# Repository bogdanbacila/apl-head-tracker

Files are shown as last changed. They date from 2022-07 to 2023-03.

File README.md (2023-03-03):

# APL Head Tracker

## A basic inexpensive head tracker based on the GY-521/MPU6050 sensor and [MrHeadTracker](https://git.iem.at/DIY/MrHeadTracker) project 

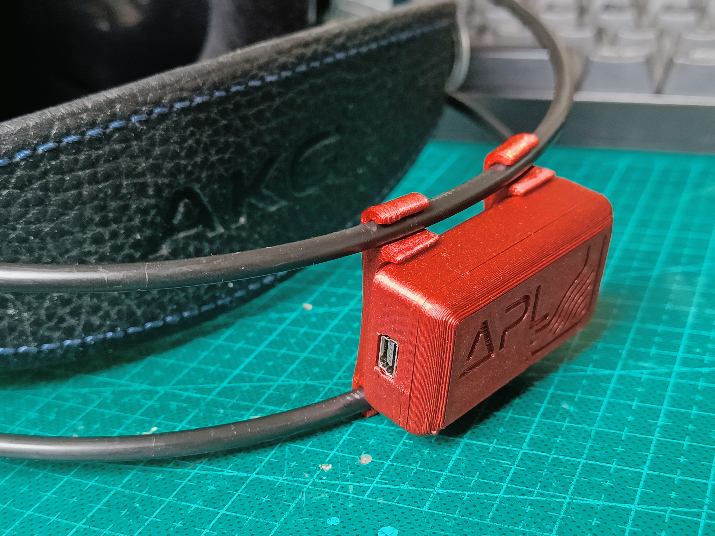
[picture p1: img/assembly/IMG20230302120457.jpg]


A head simple head tracker which connects to the computer through a USB cable and communicates rotation information through serial messaging, in both quaternion and YPR angles.

This head tracker is designed to work best with the APL OSC Bridge. 

### Requirements:

> The Amazon links are shown for illustrative purposes. You can source the parts from the supplier that is most convenient for you.

- 1 pc. Arduino Nano V3 - (recommended the mini-usb version). [Amazon link](https://www.amazon.co.uk/ELEGOO-ATmega-Nano328P-compatible-offical/dp/B072BMYZ18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)
- 1 pc. GY-521/MPU6050 IMU [Amazon link](https://www.amazon.co.uk/AZDelivery-MPU-6050-Gyroscope-Accelerometer-Arduino/dp/B07N2ZL34Z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)
- 1 pc. APL tracker PCB shield: GRBL and SVG files can be found in the [pcb-shield](/pcb-shield/) folder, for home-manufacturing of the PCB shield. Alternatively, PCB shields could be professionally manufactured by companies such as JLCPCB, PCBWay, etc. 
- 1 pc. Micro push button (6 x 6 x 5 mm). [Amazon link](https://www.amazon.co.uk/Youmile-100-Pack-Miniature-Momentary-Tactile-6-x-5-mm/dp/B07Q1BXV7T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)
- 1 pc. 2-bit DIP switch. [Amazon link](https://www.amazon.co.uk/sourcing-map-Horizontal-Positions-Breadboards/dp/B07MH6W9QD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)
- 1 pc. 7 pin header.
- 2 pc. 5 pin header.
- Enclosure: STL or 3MF files can be found [here](enclosure/) for home-printing of the enclosures. 

## Build instructions:

Make sure you have all the components available before starting the build:

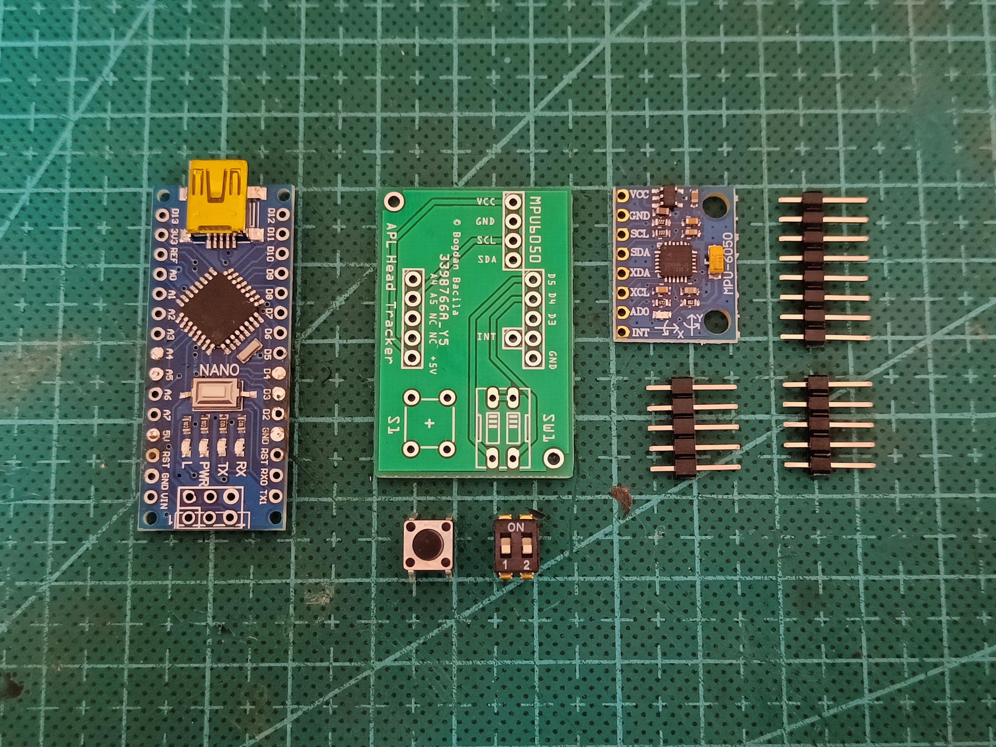
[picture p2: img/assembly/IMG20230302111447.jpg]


### **Step 1:**

Start by preparing MPU-6050 gyroscope break-out board. Solder the 7-pin header **facing up** on the board. 

>**ATTENTION!:** Do not solder pins **XDA, XCL** and **ADO**. These will be removed later. 

| | |
|-|-|
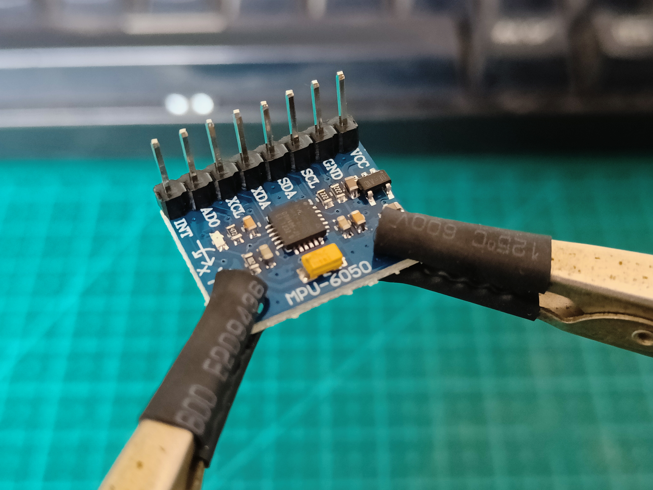
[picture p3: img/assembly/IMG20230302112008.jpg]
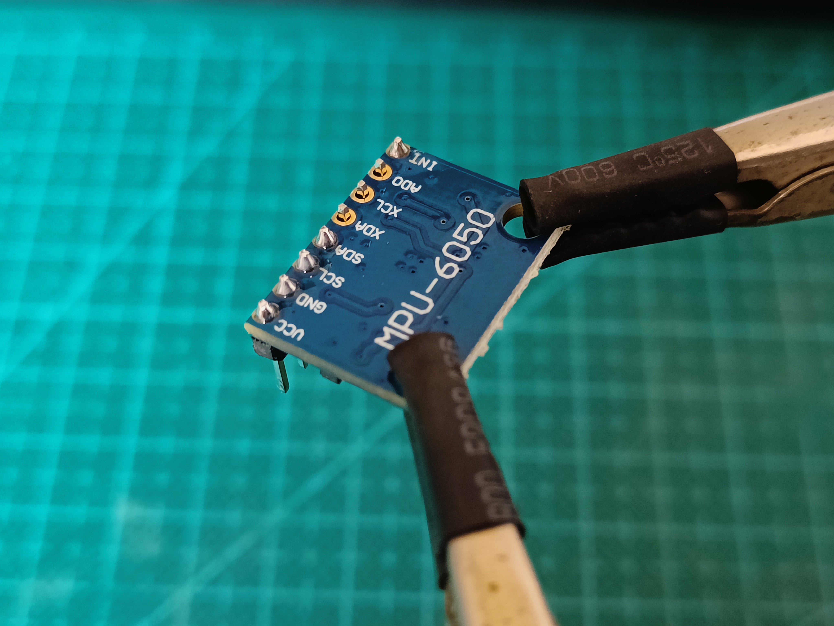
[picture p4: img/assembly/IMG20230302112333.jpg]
|||

Using a pair of pliers, carefully remove pins **XDA, XCL** and **ADO**:

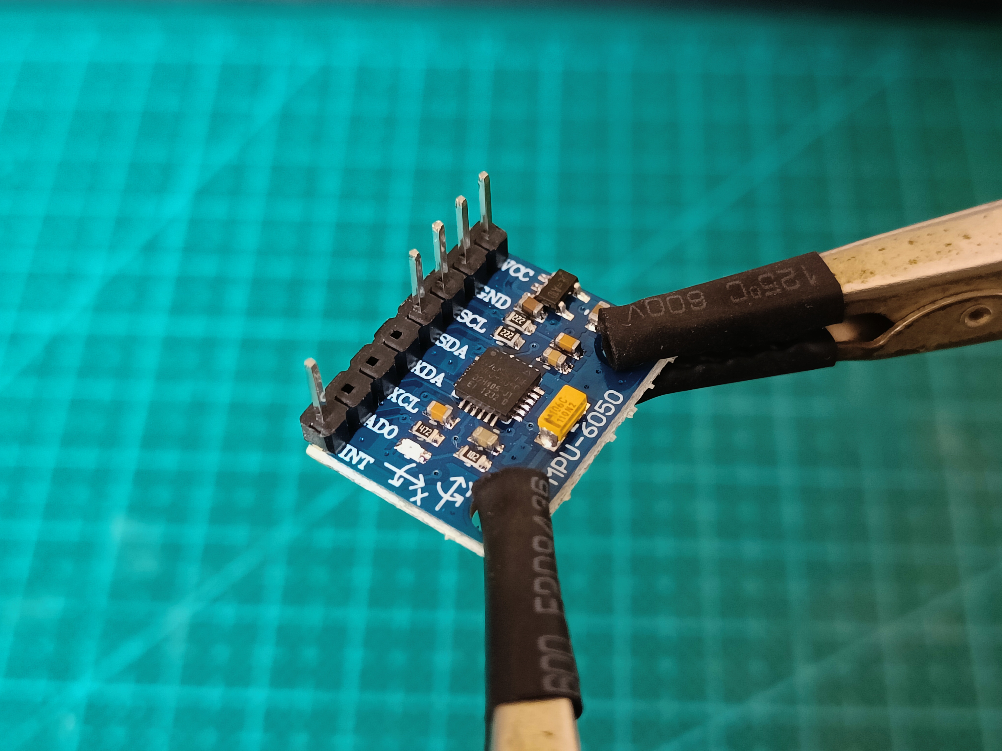
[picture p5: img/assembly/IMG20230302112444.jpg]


### **Step 2:**

Prepare the PCB shield: 

Start by soldering the micro-switch and the 2-pin dip-switch. 

| | |
|-|-|
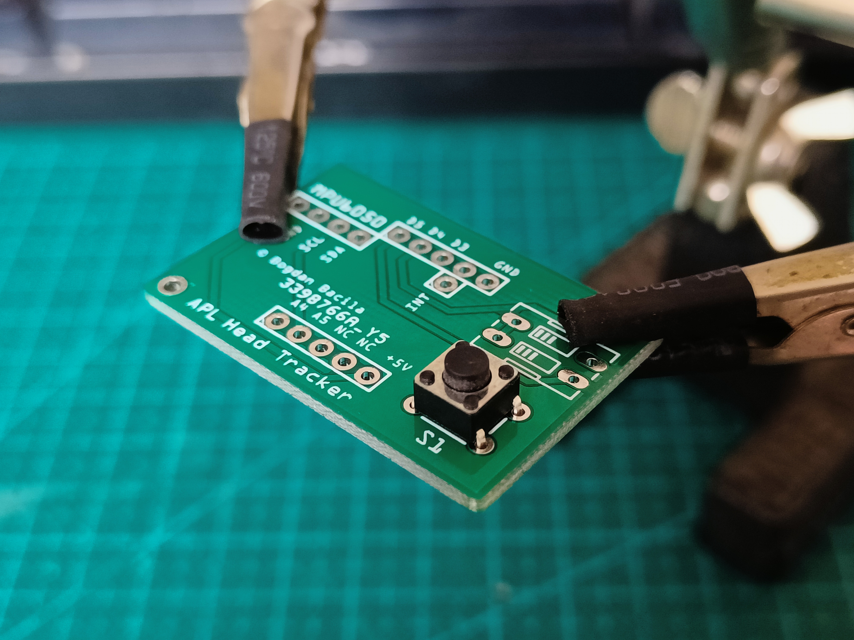
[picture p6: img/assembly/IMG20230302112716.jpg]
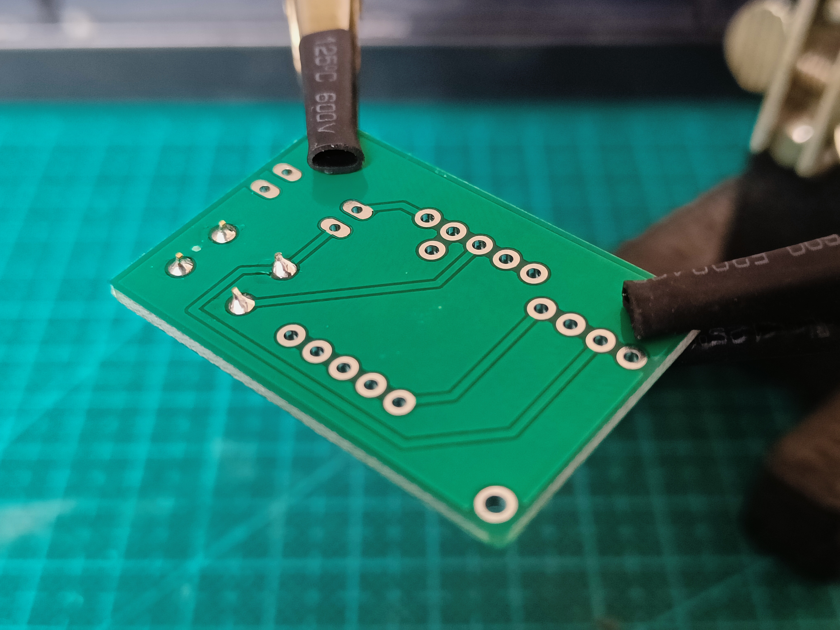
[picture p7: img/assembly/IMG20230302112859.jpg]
||
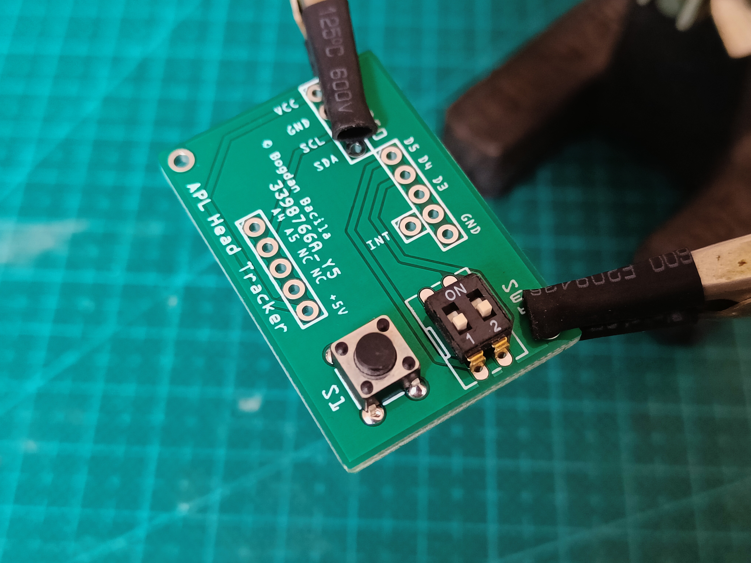
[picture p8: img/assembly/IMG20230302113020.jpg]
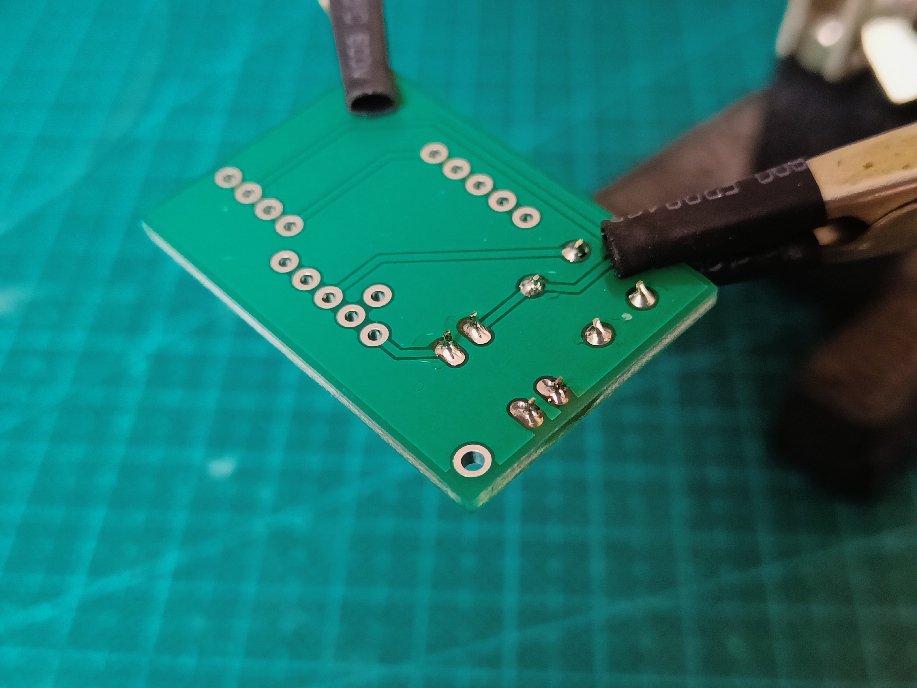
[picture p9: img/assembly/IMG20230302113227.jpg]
||

Next, solder the two 5-pin headers to the **bottom** of the PCB shield. Make sure they are soldered square to the board, otherwise it may not fit properly to the Arduino. 

| | |
|-|-|
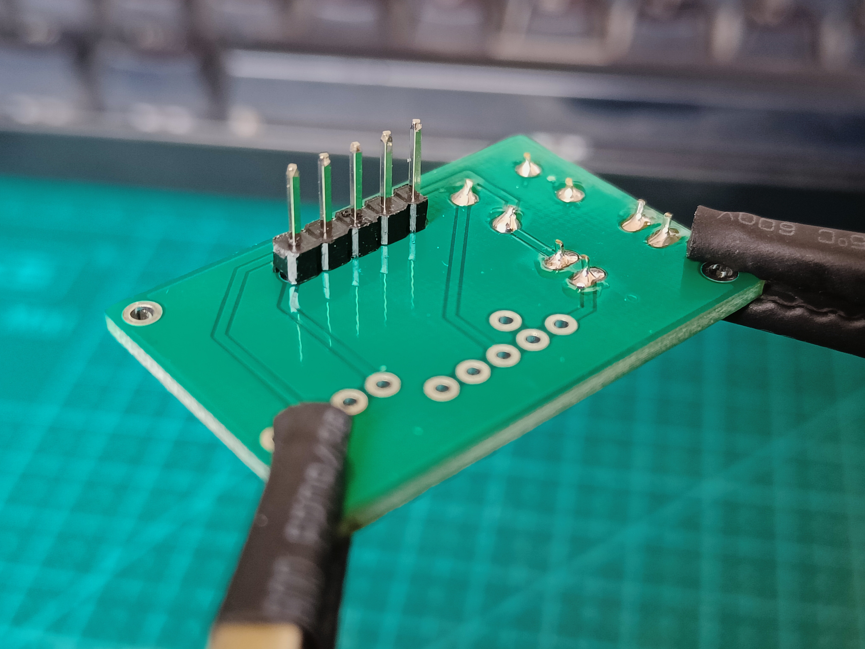
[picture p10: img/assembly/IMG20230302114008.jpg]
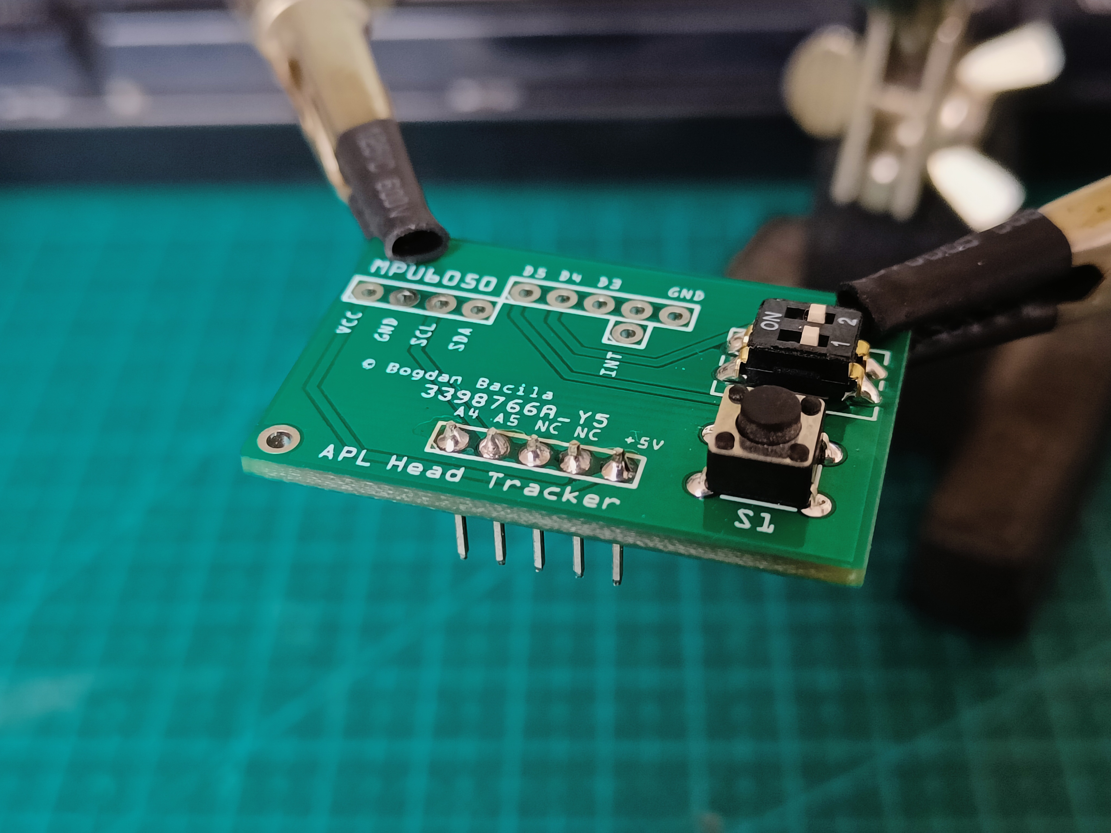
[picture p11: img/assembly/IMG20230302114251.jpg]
||
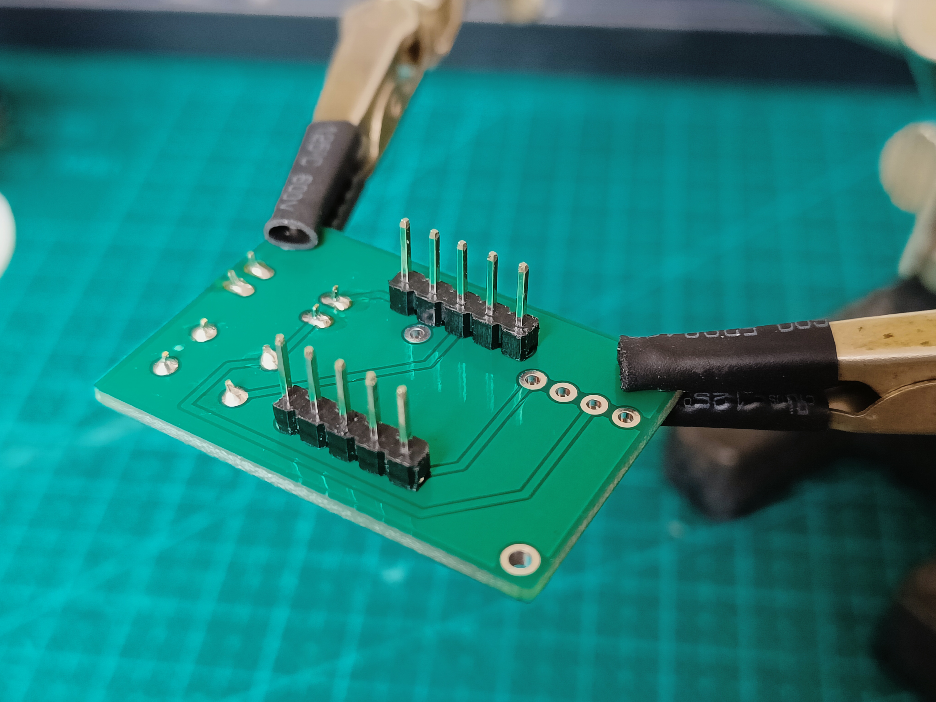
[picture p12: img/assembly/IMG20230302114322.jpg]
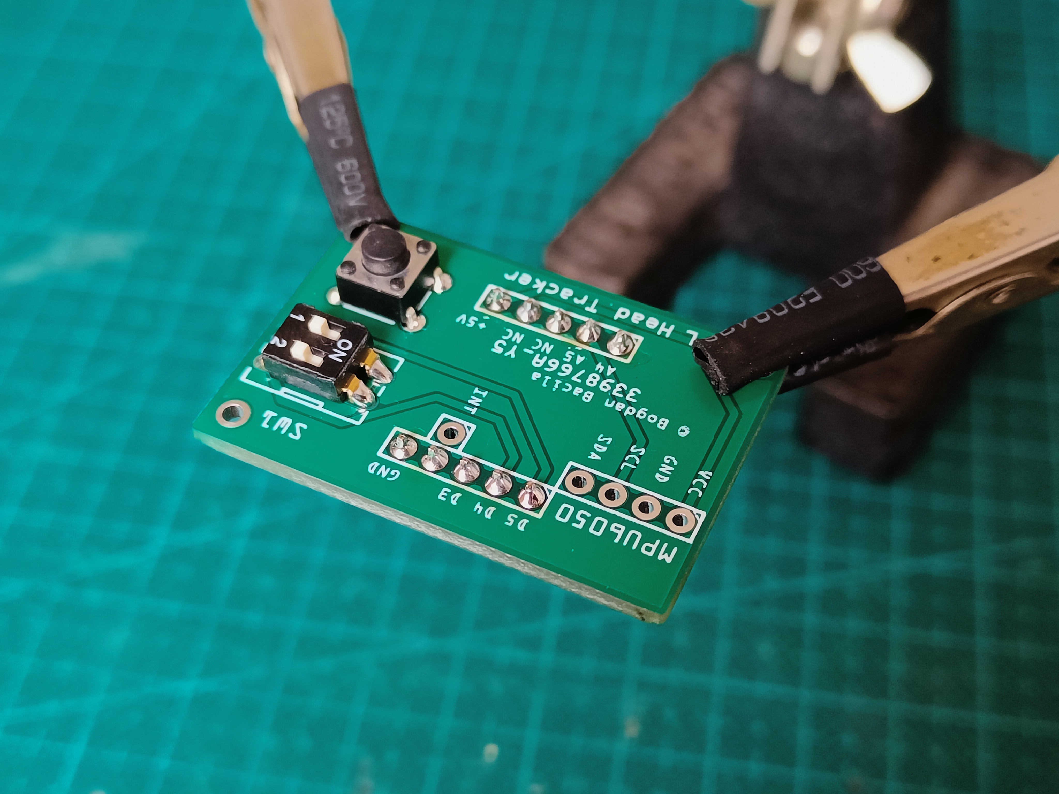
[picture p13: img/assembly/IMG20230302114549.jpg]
||

### **Step 3:**

Solder the MPU-6050 to the **top** of PCB shield, making sure to match the pins on the gyroscope to the pins written on the shield. 

| | |
|-|-|
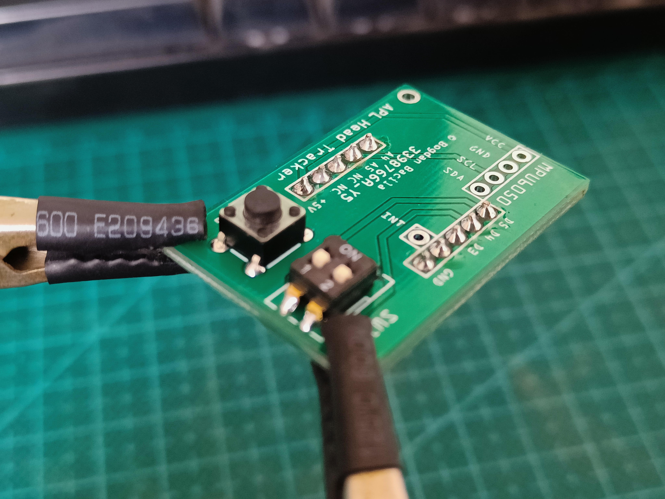
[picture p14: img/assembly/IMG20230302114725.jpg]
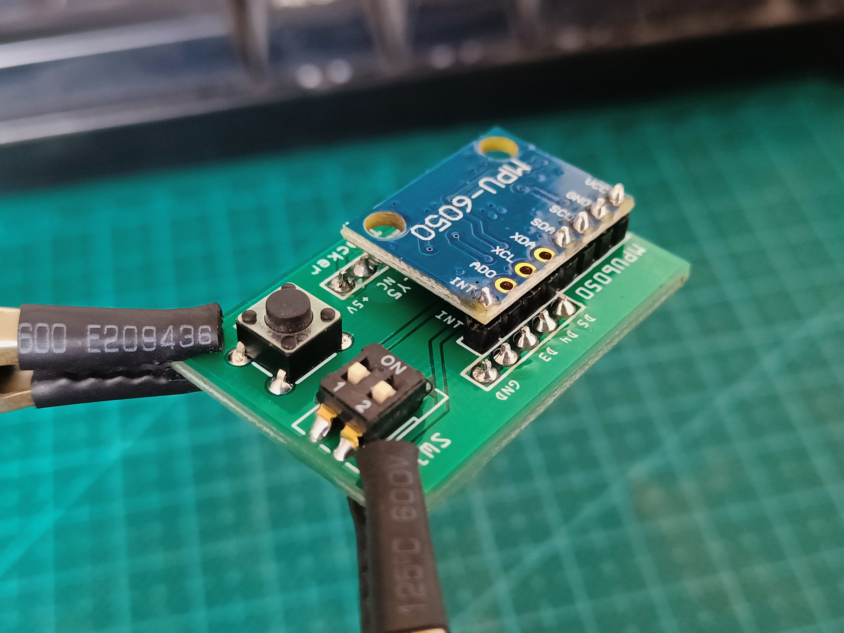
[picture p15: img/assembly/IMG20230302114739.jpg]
||

With a pair of flush cutters, carefully cut the excess header pins from the bottom of the PCB shield. This is necessary to ensure the shield can be soldered flush to the Arduino. 

| | |
|-|-|
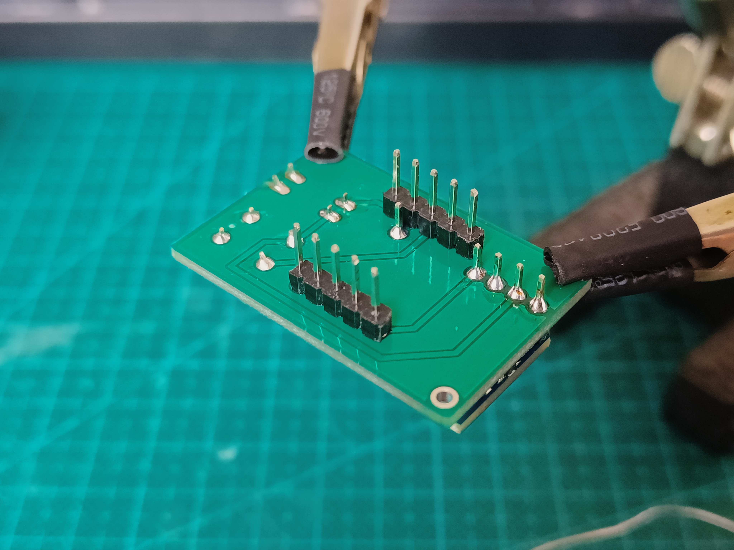
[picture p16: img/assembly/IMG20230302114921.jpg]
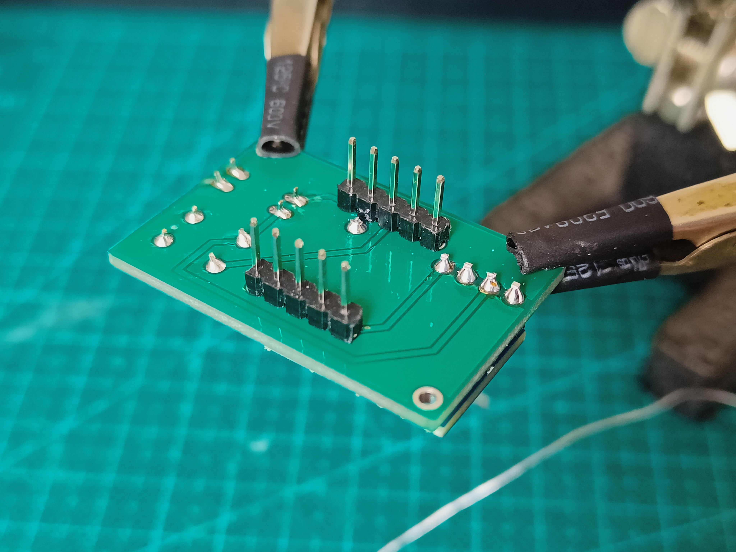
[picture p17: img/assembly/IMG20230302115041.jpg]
||

You have now built the core of the head tracker!

| | |
|-|-|
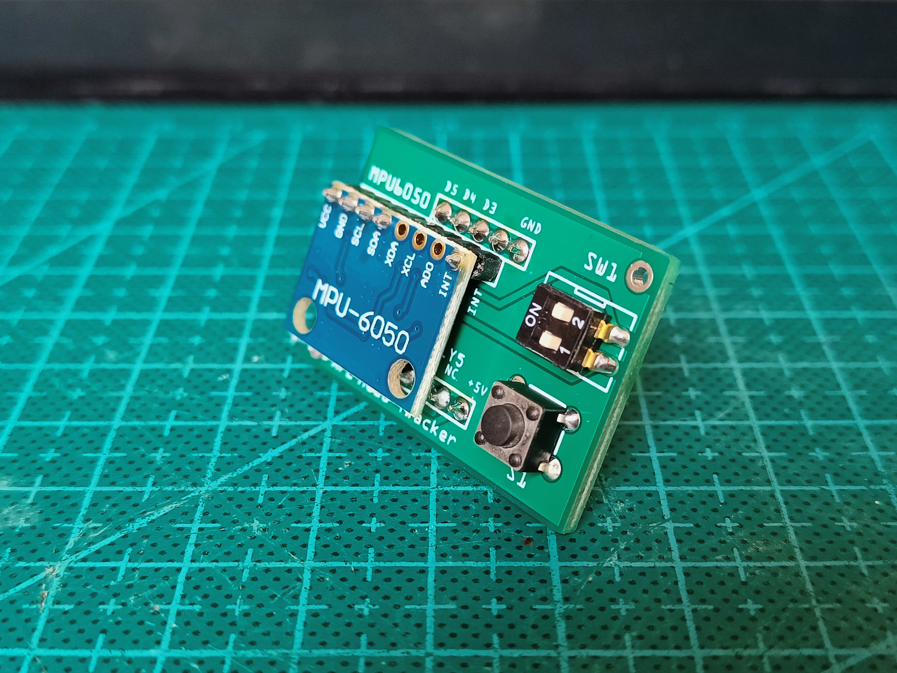
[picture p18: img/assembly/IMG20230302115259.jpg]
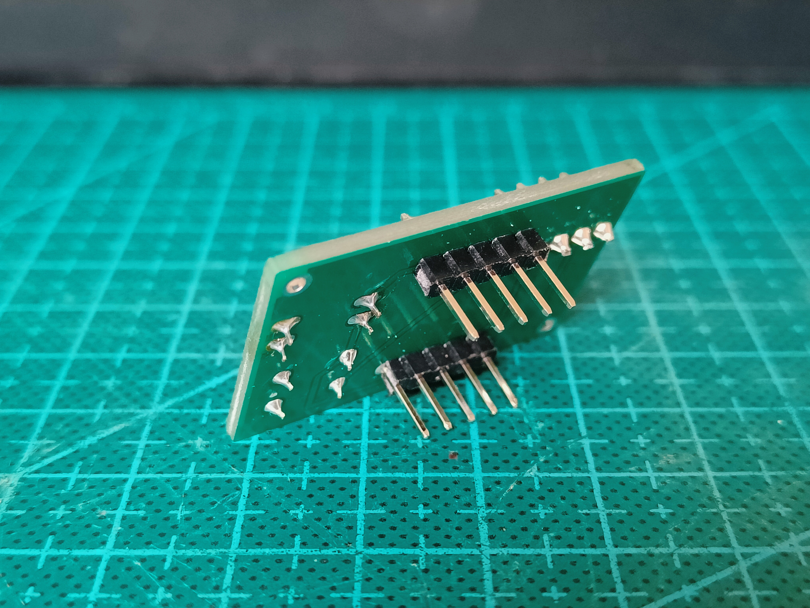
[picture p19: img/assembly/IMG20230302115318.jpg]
||

### **Step 4:**

Solder the PCB shield to the **top** of Arduino, making sure to match the pins on the shield to the pins on the Arduino. Snip the excess pins flush to the Arduino board to ensure a good fit in the enclosure. 

| | |
|-|-|
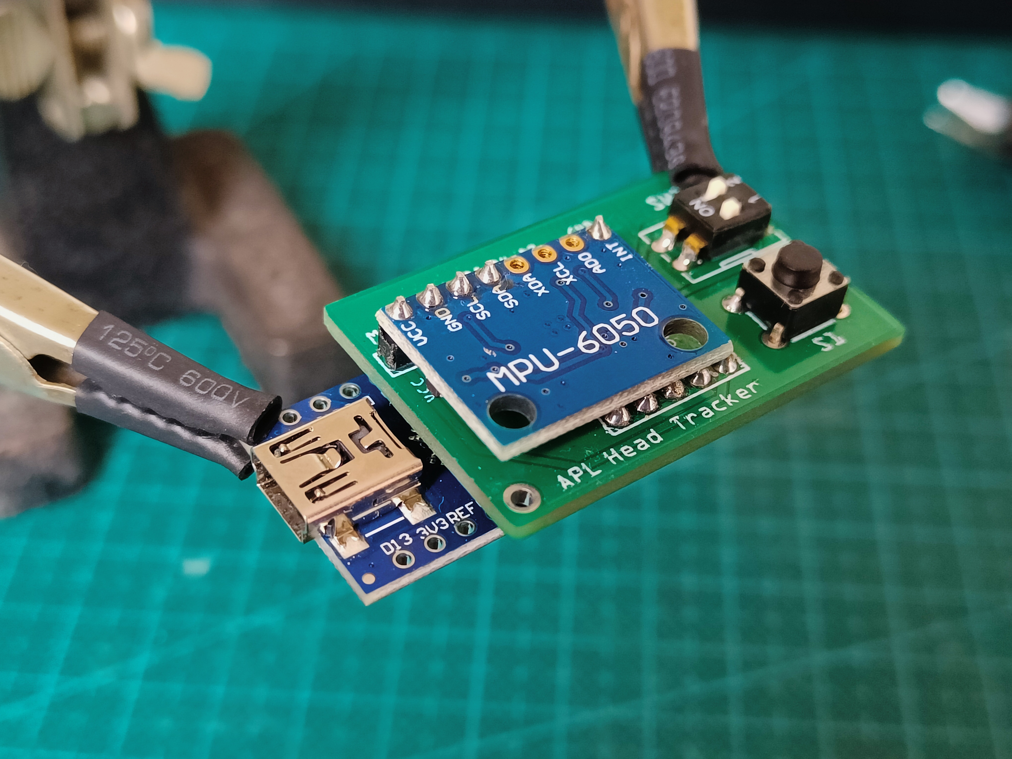
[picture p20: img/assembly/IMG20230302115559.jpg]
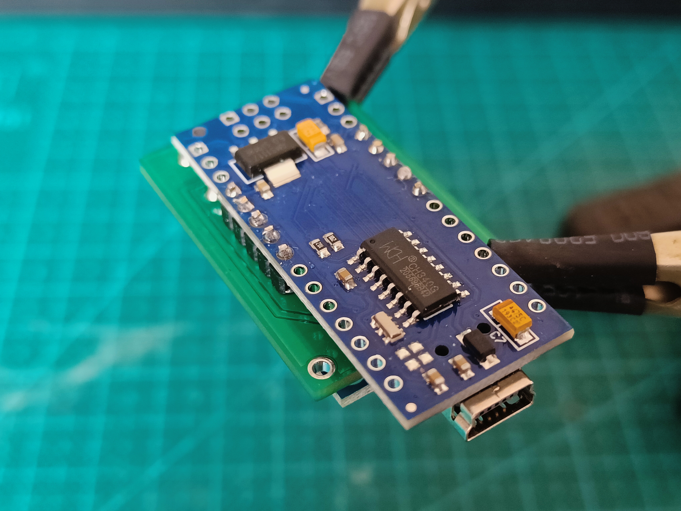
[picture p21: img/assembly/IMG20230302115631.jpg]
||

Now you can set the micro switches as desired: 

- Switch No.1 changes between Quaternions and Yaw-Pitch-Roll output
- Switch No.2 changes between normal and inverse 

To ensure compatibility with the APL OSC bridge, please set the switches as seen in the pictures above: switch no.1 set to on and switch no.2 set to off.

The electronic part of the head tracker is now finished, and you can start using it after flashing the firmware. However, if you own a 3D printer, you can also print an enclosure from the [STLs](/enclosure/) provided:

### **Step 5:**

Make sure all the parts are printed. If additional cleaning of the prints (de-burring or sanding) is required, this would be a great moment for it. Place the head tracker in the enclosure, making sure that the USB port fits the slot in the side. The tracker should be held in place in the enclosure by friction alone. If the fit is tighter than expected, do not force it in, this may damage the enclosure or the PCB; slightly file (or sand) down the edges of the PCB until it fits well. If the fit is loose, you may apply a slight bead of glue between the PCB and the enclosure shelf, to ensure that it does not move.

After ensuring that the tracker does not move in the enclosure, you can now put the lid on. This should just snap in place. Make sure the button lines up with the micro-switch. Test the functionality of the button. You should feel a definite click produced by the button. 

| | |
|-|-|
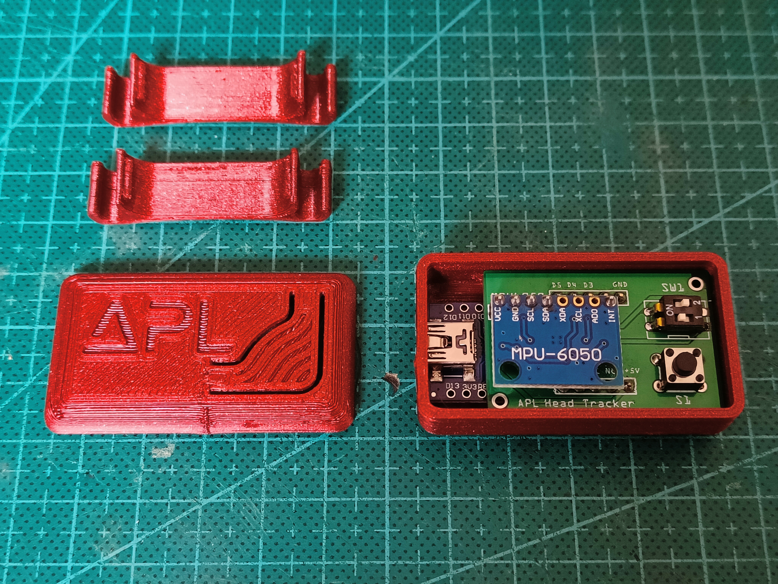
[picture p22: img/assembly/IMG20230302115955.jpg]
||
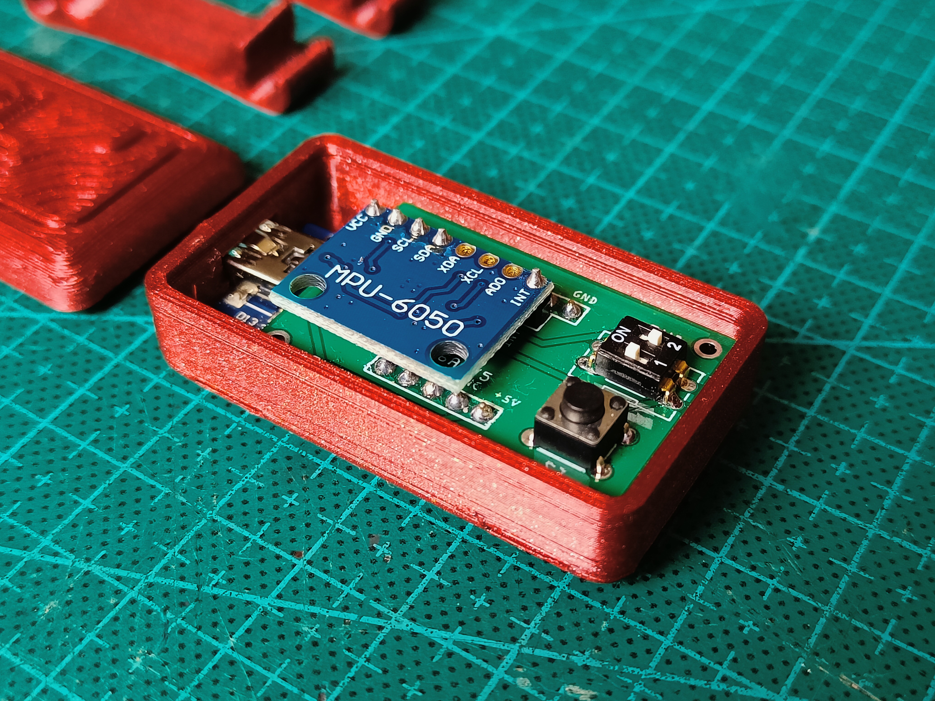
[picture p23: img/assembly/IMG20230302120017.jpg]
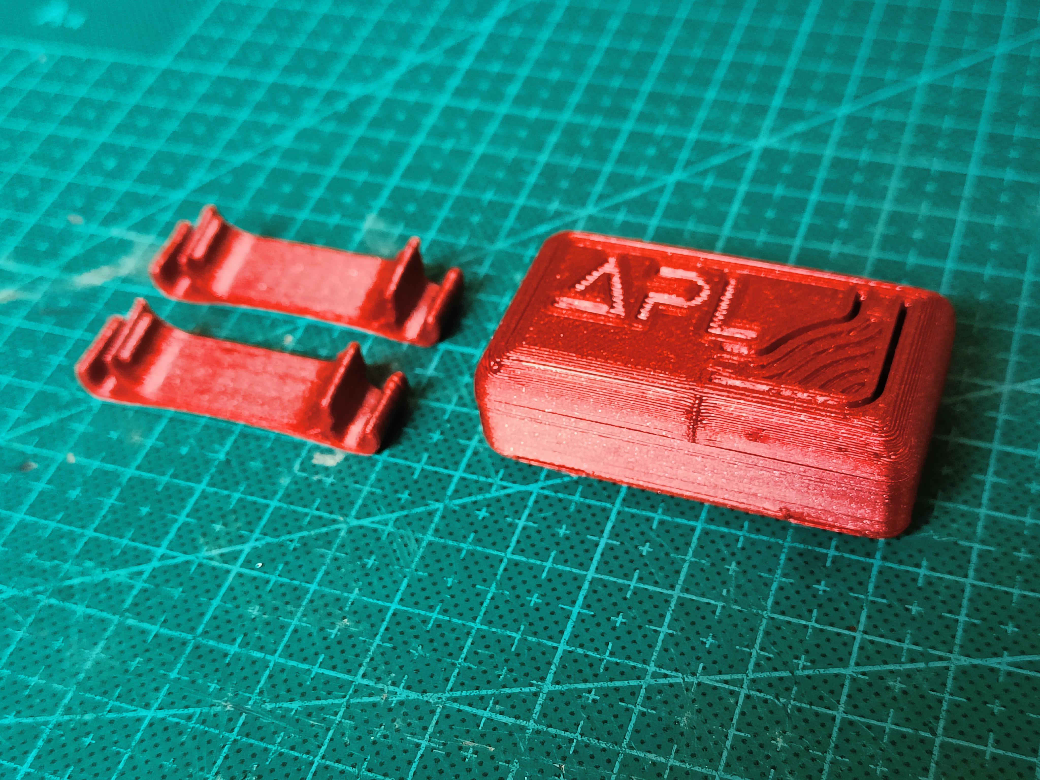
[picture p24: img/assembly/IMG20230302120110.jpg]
||

Next, clip the feet to the bottom of the enclosure. Make sure that the orientation matches the one shown in the following picture.

| | |
|-|-|
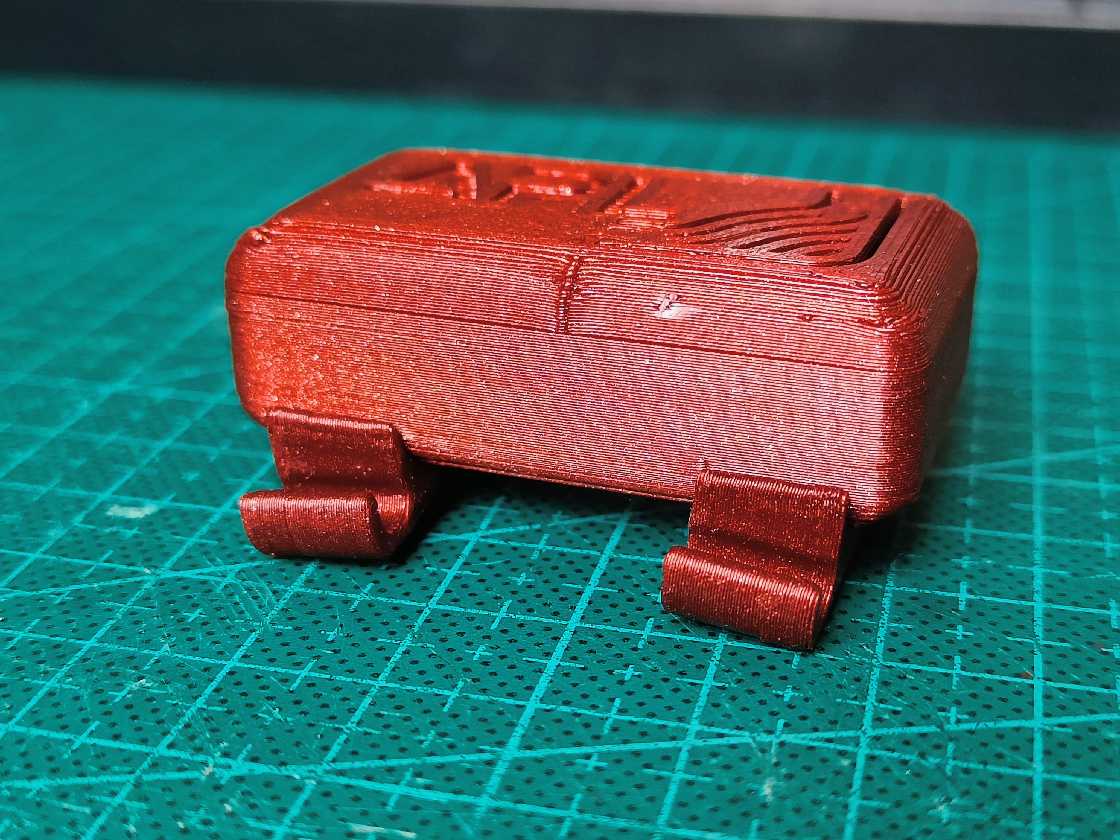
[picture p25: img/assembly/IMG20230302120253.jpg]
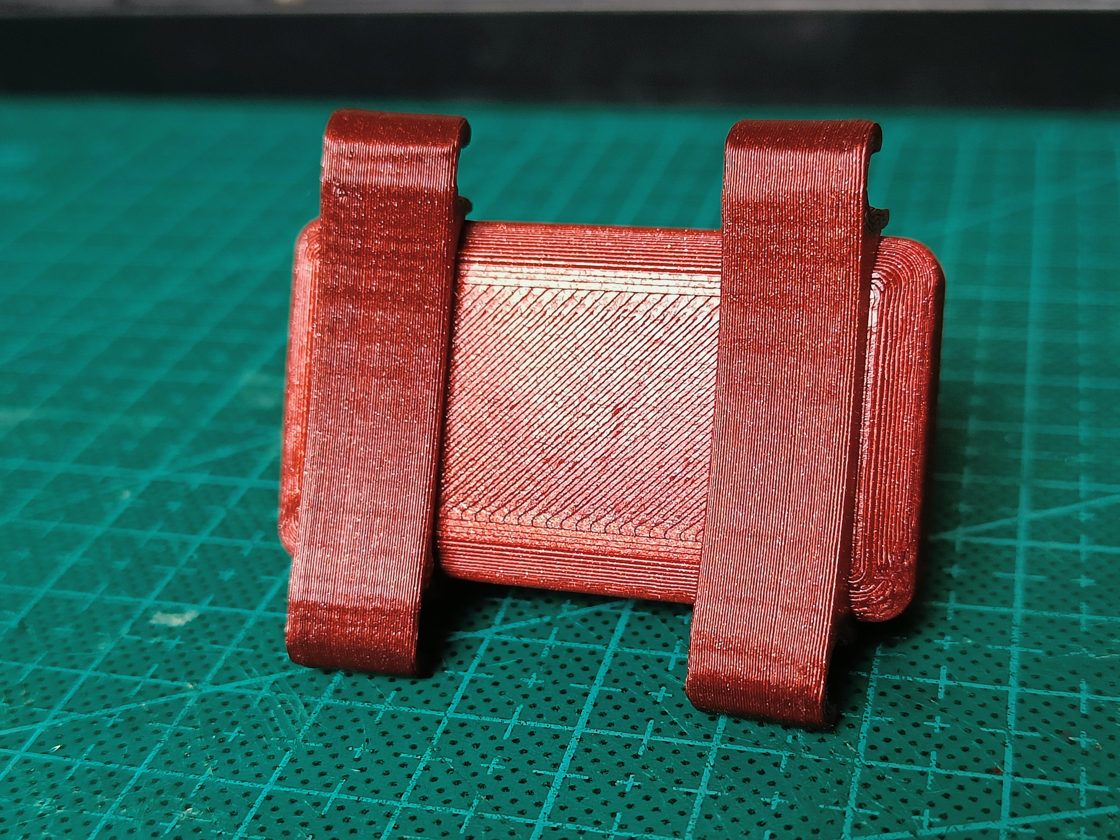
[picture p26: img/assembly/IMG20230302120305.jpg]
||

### **Congratulations!** You now have a new head tracker! 

| | |
|-|-|
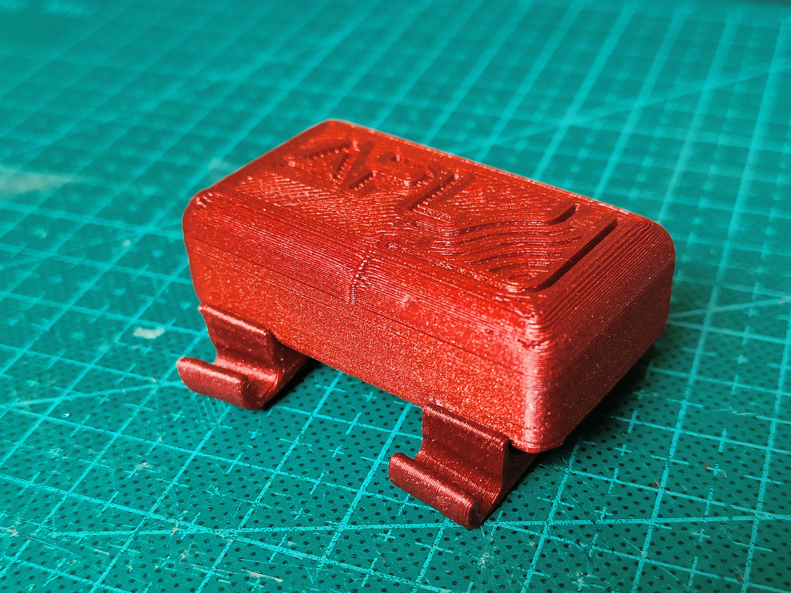
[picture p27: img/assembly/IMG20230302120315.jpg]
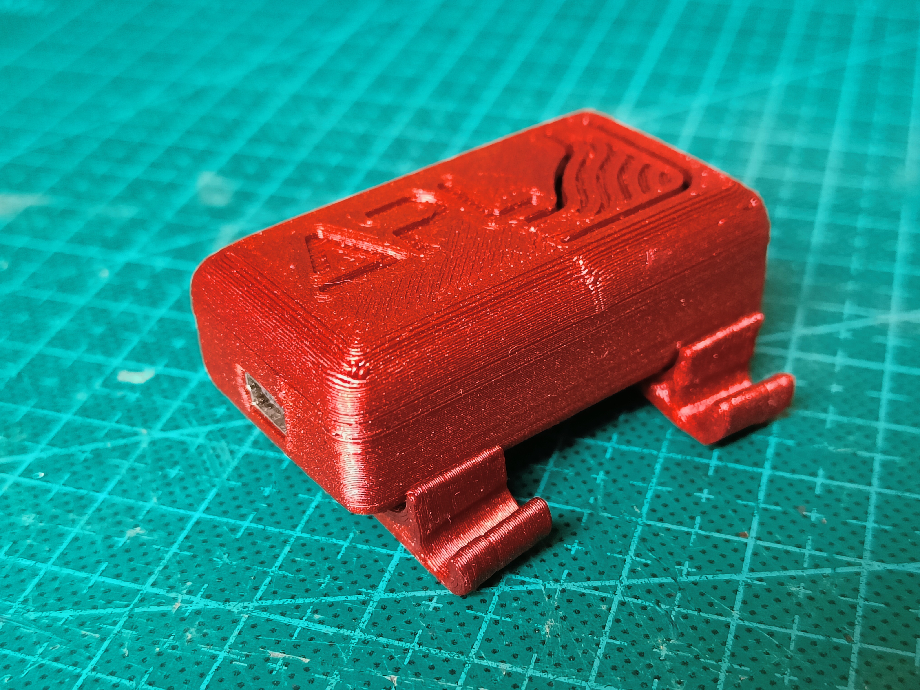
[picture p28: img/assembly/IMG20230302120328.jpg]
||
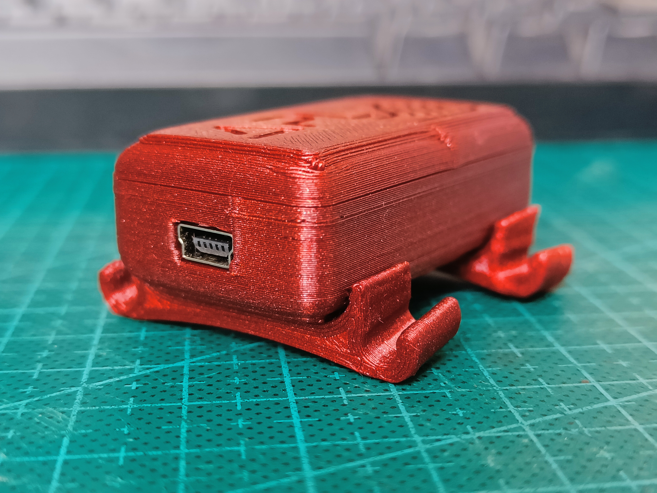
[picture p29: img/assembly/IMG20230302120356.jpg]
||

The tracker can be easily clipped to AKG-style headbands, directly on the wire frames. Alternatively, the tracker can also be mounted to a wide range of other headphones, by using an elastic hairband as shown below. 

| | |
|-|-|
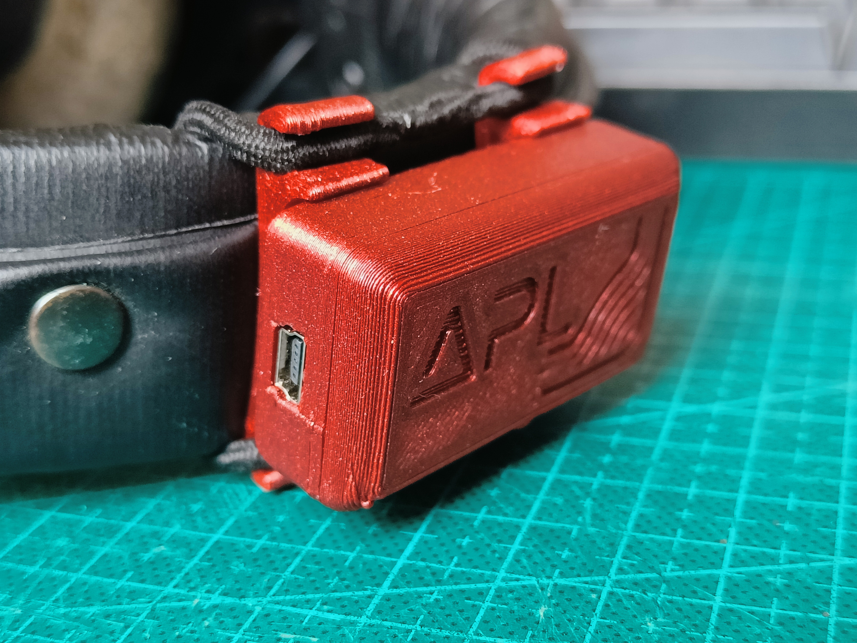
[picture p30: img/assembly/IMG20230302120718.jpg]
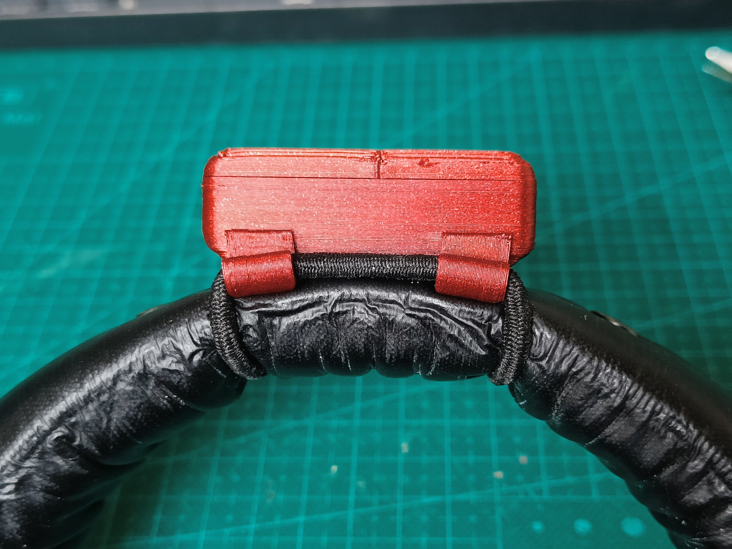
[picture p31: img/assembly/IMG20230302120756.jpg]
|| 

## Flashing the firmware

### **Step 1:**

1. Download and install the Arduino IDE from https://www.arduino.cc/en/software
2. Connect your head tracker to your computer using a USB cable.

### **Step 2:**

Install the "MIDI" and "MPU6050" [libraries](/arduino/apl-head-tracker/libraries/) (found in this repository, in the `/arduino/apl-head-tracker/libraries/` directory):
  
  1. `Sketch -> Include Library -> Add .ZIP Library`
  2. Add the "MIDI" and "MPU6050" libraries one at a time, using the step above. 

### **Step 3:**

Upload [`apl-head-tracker.ino`](arduino/apl-head-tracker/apl-head-tracker.ino) to your head tracker:

1. Choose your board from `Tools -> Boards -> Arduino AVR boards -> Arduino Nano`
2. Choose the port on which you have connected your head tracker from `Tools -> Port -> YOUR_SERIAL_PORT_HERE`

> INFO: You may have to check if your Arduino board is supported. If the board is using a WCH usb-to-serial converter you may need to install additional drivers in order to be recognised.

1. Press the "Upload" button. If not successful at first, try changing the processor (`Tools -> Processor`) from `ATmega320P` to `ATmega320P (Old Bootloader)` or vice-versa. When the upload is successful you will receive the message 'Done upoading'. 

### Congratulations! You have just flashed the firmware to your head tracker. 

>  You can also verify if the tracker works properly by opening the 'Serial Monitor' (magnifying glass icon in the top-right corner). After the initial calibration (described below) four numbers will show on the screen according to the `w x y z` values (if quaternion is selected) or `yaw pitch roll` (if `ypr` is selected)

Once the tracker is initialized and calibrated to your desired frontal position, the rotation axes are as shown in the following diagram. 

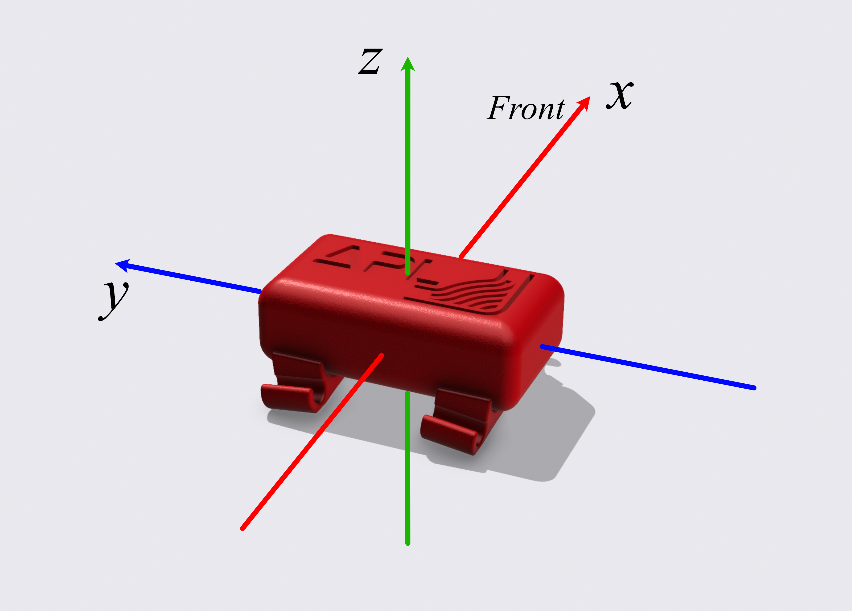
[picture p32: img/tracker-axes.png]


## Calibrating the head tracker

The APL head tracker uses the same calibration method as [MrHeadTracker](https://git.iem.at/DIY/MrHeadTracker). You can mount the tracker in any position or orientation and follow the next steps:

1. Look straight ahead. Press the button for longer than 1 second (Long press)
2. Tilt your head down, looking at the floor. Press the button shortly. (Short press)
3. Look back up. The tracker should now be calibrated, and the position will be stored in the Arduino's EEPROM. You should only repeat this steps when changing the position of the head tracker. 

> **If the head tracker drifts (it will)** you can keep pressing the button shortly (short press < 1s) to re-centre. The tracker will benefit from moving it in a figure-of-8 pattern until it stabilizes. It will also stabilize in time, so it would be also worth considering plugging the tracker in a few minutes prior to using it.

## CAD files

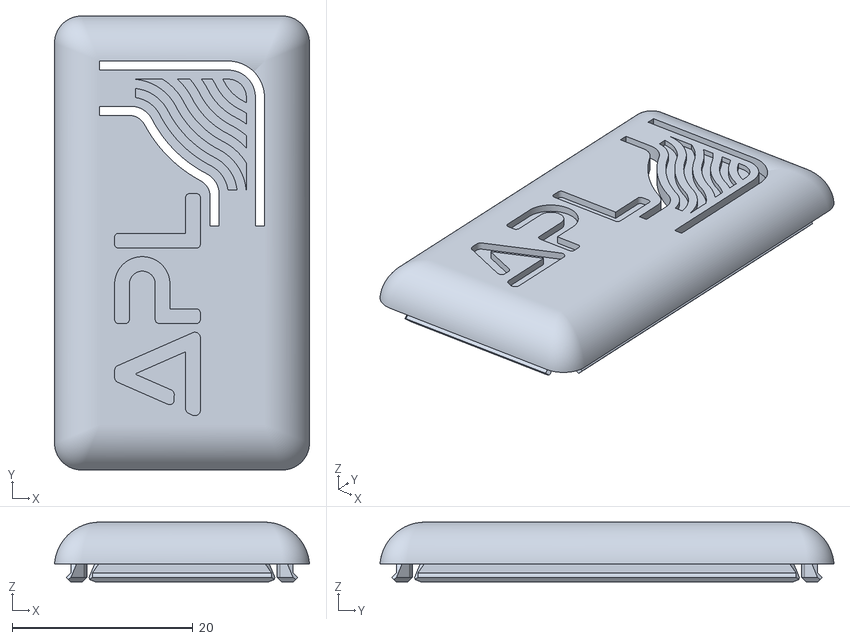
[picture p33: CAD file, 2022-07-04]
enclosure/stl/apl-head-tracker-enclosure-lid.stl
28.2 x 50.2 x 6.60

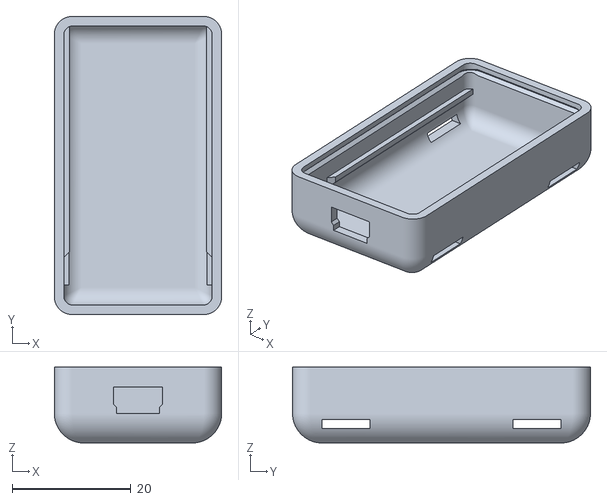
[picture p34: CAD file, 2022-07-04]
enclosure/stl/apl-head-tracker-enclosure-body.stl
28.2 x 50.2 x 12.8

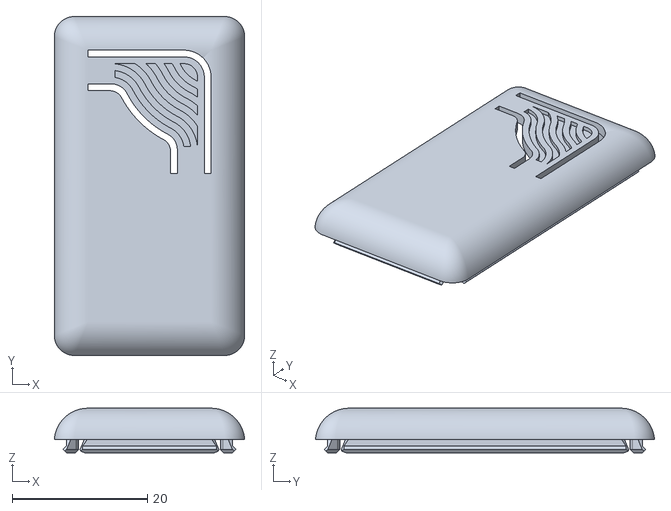
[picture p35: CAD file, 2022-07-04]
enclosure/stl/apl-head-tracker-enclosure-lid-no-logo.stl
28.2 x 50.2 x 6.60

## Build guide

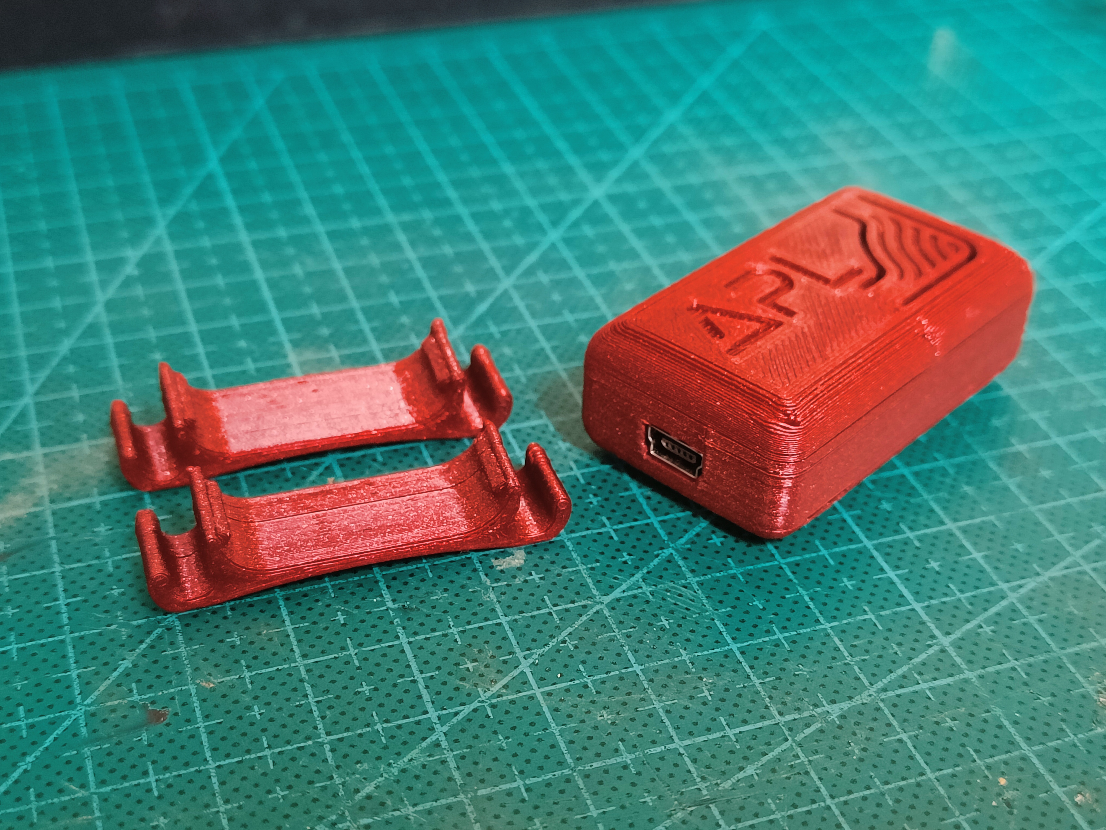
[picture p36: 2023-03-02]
img/assembly/IMG20230302120147.jpg

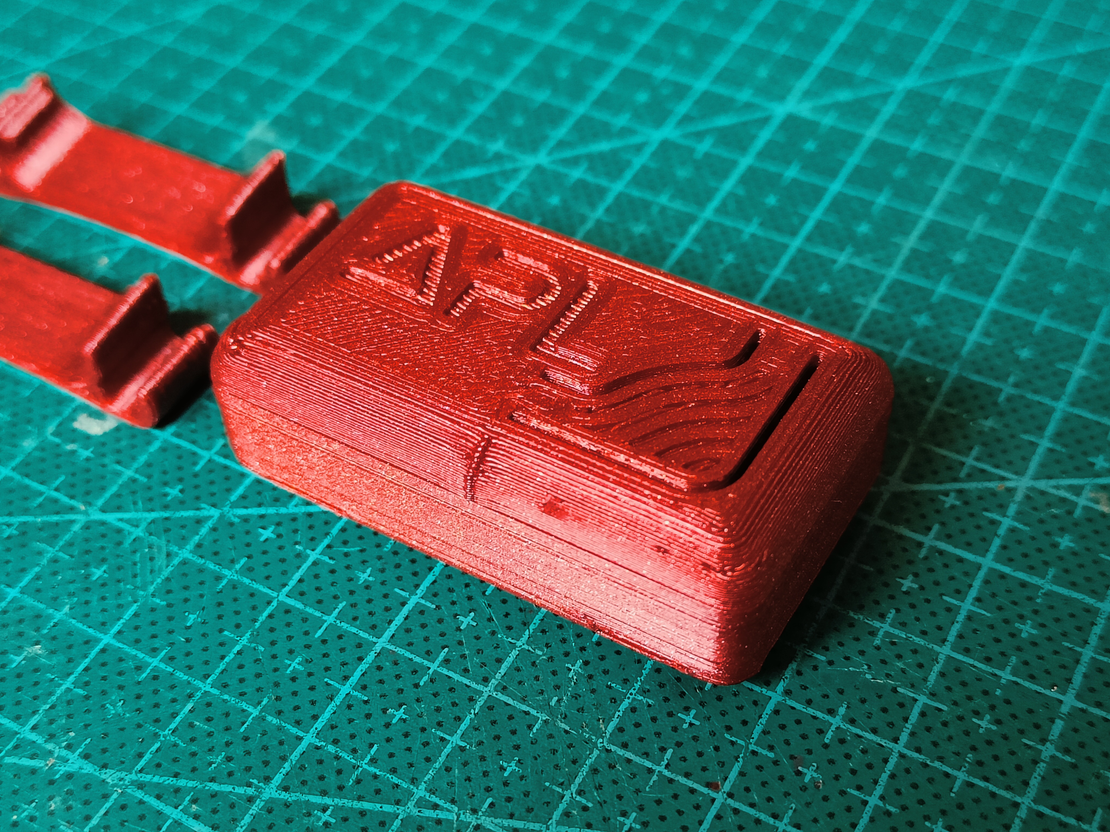
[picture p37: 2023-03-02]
img/assembly/IMG20230302120209.jpg

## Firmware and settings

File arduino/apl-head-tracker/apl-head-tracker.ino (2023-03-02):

/*
    APL head tracker - a basic inexpensive head tracker based on the GY-521/MPU6050 sensor
    
    APL head tracker is based on MrHeadTracker Switchable (Copyright (C) 2016-2017  Michael Romanov, Daniel Rudrich)
    
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
    You should have received a copy of the GNU General Public License
    along with this program.  If not, see <http://www.gnu.org/licenses/>.
*/


#include <EEPROM.h>
#include <Wire.h>
#include <MIDI.h>
#include <MPU6050_6Axis_MotionApps20.h>
#include "utility/imumaths.h"

// MIDI
MIDI_CREATE_DEFAULT_INSTANCE();

// Pins and Settings
#define LED 13
#define button 3 // <-- should be an interrupt pin
#define invSwitch 4       //switch #2 on tracker
#define quatSwitch 5      //switch #1 on tracker
#define pi 3.1415926536
#define radTo14 2607.594587617613379
#define oneTo14 8191
#define qCalAddr 0 // EEPROM qCal address
#define debounceDelay 50

//APL head tracker is optimised to function with serial communication
//However, the MIDI functionality of the original MrHeadTracker is still preserved
//This can be switched on by uncommenting the MODE_MIDI flag and commenting MODE_SERIAL

#define MODE_SERIAL
//#define MODE_MIDI


volatile unsigned long lastChangeTime, lastPressTime, lastReleaseTime = 0;
volatile bool buttonState = 1;
volatile bool newButtonState = 0;
int action = 0;
int calibrationState = 0;

uint16_t lastW = 63;
uint16_t newW = 63;
uint16_t lastX = 63;
uint16_t newX = 63;
uint16_t lastY = 63;
uint16_t newY = 63;
uint16_t lastZ = 63;
uint16_t newZ = 63;

// MPU control/status vars
MPU6050 mpu;
bool dmpReady = false;  // set true if DMP init was successful
uint8_t mpuIntStatus;   // holds actual interrupt status byte from MPU
uint8_t devStatus;      // return status after each device operation (0 = success, !0 = error)
uint16_t packetSize;    // expected DMP packet size (default is 42 bytes)
uint16_t fifoCount;     // count of all bytes currently in FIFO
uint8_t fifoBuffer[64]; // FIFO storage buffer

// Quaternions and Vectors
Quaternion qCal, qCalLeft, qCalRight, qIdleConj = {1, 0, 0, 0};
Quaternion qGravIdle, qGravCal, quat, steering, qRaw;

VectorInt16 gRaw;         //
const VectorFloat refVector = {1, 0, 0};
VectorFloat vGravIdle, vGravCal;
float ypr[3]; //yaw pitch and roll angles

// Interrupt detection - sensor
volatile bool mpuInterrupt = false;     // indicates whether MPU interrupt pin has gone high
void dmpDataReady() {
  mpuInterrupt = true;
}



// ================================================================
// ===                      INITIAL SETUP                       ===
// ================================================================

void setup() {
  // join I2C bus (I2Cdev library doesn't do this automatically)
  Wire.begin();


  
  #ifdef MODE_SERIAL
  Serial.begin(115200, SERIAL_8E1);
  #endif

  #ifdef MODE_MIDI
  MIDI.begin(MIDI_CHANNEL_OMNI); // use this with HIDUINO
  #endif

  pinMode(button, INPUT_PULLUP);
  pinMode(invSwitch, INPUT_PULLUP);
  pinMode(quatSwitch, INPUT_PULLUP);
  attachInterrupt(digitalPinToInterrupt(button), buttonChange, CHANGE);

  pinMode(LED, OUTPUT);
  digitalWrite(LED, LOW);
  EEPROM.get(qCalAddr, qCal); // read qCal from EEPROM and print values
  resetOrientation();

  // initialize device
  mpu.initialize();
  // wait for ready
  while (Serial.available() && Serial.read()); // empty buffer again
  // load and configure the DMP
  devStatus = mpu.dmpInitialize();
  // make sure it worked (returns 0 if so)
  if (devStatus == 0) {
    // turn on the DMP, now that it's ready
    delay(5);
    // Serial.println(F("Enabling DMP..."));
    mpu.setDMPEnabled(true);

    // enable Arduino interrupt detection
    //Serial.println(F("Enabling interrupt detection (Arduino external interrupt 0)..."));
    attachInterrupt(digitalPinToInterrupt(2), dmpDataReady, RISING);
    mpuIntStatus = mpu.getIntStatus();

    // set our DMP Ready flag so the main loop() function knows it's okay to use it
    //Serial.println(F("DMP ready! Waiting for first interrupt..."));
    dmpReady = true;
    // get expected DMP packet size for later comparison
    packetSize = mpu.dmpGetFIFOPacketSize();
  }
}



// ================================================================
// ===                    MAIN PROGRAM LOOP                     ===
// ================================================================

void loop() {
  // ============== BUTTON CHECK ROUTINE ==========================
  action = 0; // do nothing, just chill... for now!

  if (newButtonState && (millis() - lastChangeTime > debounceDelay)) {
    switch (buttonState) {
      case 0: // pressed
        lastPressTime = lastChangeTime;
        if (millis() - lastPressTime > 1000) {
          action = 2; //held longer than ^ ms
          newButtonState = 0; //only once!
        }
        break;
      case 1: // released
        newButtonState = 0;
        lastReleaseTime = lastChangeTime;
        action = 1; // short button click
        if (lastReleaseTime - lastPressTime > 1000) {
          action = 3; //release after hold > ^ ms
        }
        break;
    }
  }


  // if programming failed, don't try to do anything
  if (!dmpReady) return;
  // wait for MPU interrupt or extra packet(s) available
  while (!mpuInterrupt && fifoCount < packetSize) {
  }

  // reset interrupt flag and get INT_STATUS byte
  mpuInterrupt = false;
  mpuIntStatus = mpu.getIntStatus();

  // get current FIFO count
  fifoCount = mpu.getFIFOCount();

  // check for overflow (this should never happen unless our code is too inefficient)
  if ((mpuIntStatus & 0x10) || fifoCount == 1024) {
    digitalWrite(LED, HIGH);
    // reset so we can continue cleanly
    mpu.resetFIFO();
    //Serial.println(F("FIFO overflow!"));

    // otherwise, check for DMP data ready interrupt (this should happen frequently)
  } else if (mpuIntStatus & 0x02) {
    // wait for correct available data length, should be a VERY short wait
    while (fifoCount < packetSize) fifoCount = mpu.getFIFOCount();

    // read a packet from FIFO
    mpu.getFIFOBytes(fifoBuffer, packetSize);

    // track FIFO count here in case there is > 1 packet available
    // (this lets us immediately read more without waiting for an interrupt)
    fifoCount -= packetSize;


  // ============== QUATERNION DATA ROUTINE ======================
    
    // get quaternion values in easy matrix form: w x y z
    mpu.dmpGetQuaternion(&qRaw, fifoBuffer);
    mpu.dmpGetAccel(&gRaw, fifoBuffer);

    steering = qIdleConj.getProduct(qRaw);
    quat = qCalLeft.getProduct(steering);
    quat = quat.getProduct(qCalRight);

    if (digitalRead(invSwitch) == LOW) {
      quat = quat.getConjugate();
    }




 // ============== SEND MIDI ROUTINE ===========================
    if (digitalRead(quatSwitch) == LOW) { //send quaternion data
    
    #ifdef MODE_SERIAL
    
    newW = (uint16_t)(1000 * (quat.w + 1));
    newX = (uint16_t)(1000 * (quat.x + 1));
    newY = (uint16_t)(1000 * (quat.y + 1));
    newZ = (uint16_t)(1000 * (quat.z + 1));

    if (newW != lastW || newX != lastX || newY != lastY || newZ != lastZ ) {
    
      sendQuaternion(newW, newX, newY, newZ);
    
    }
    #endif

    
    #ifdef MODE_MIDI

    newW = (uint16_t)(oneTo14 * (quat.w + 1));
    newX = (uint16_t)(oneTo14 * (quat.x + 1));
    newY = (uint16_t)(oneTo14 * (quat.y + 1));
    newZ = (uint16_t)(oneTo14 * (quat.z + 1));
    
    if (newW != lastW) {  
      MIDI.sendControlChange(48, newW & 0x7F,  1);
      MIDI.sendControlChange(16, (newW >> 7) & 0x7F, 1);
    }
    if (newX != lastX) {  
      MIDI.sendControlChange(49, newX & 0x7F,  1);
      MIDI.sendControlChange(17, (newX >> 7) & 0x7F, 1);
    }
    if (newY != lastY) {
      MIDI.sendControlChange(50, newY & 0x7F, 1);
      MIDI.sendControlChange(18, (newY >> 7) & 0x7F, 1);  
    }
    if (newZ != lastZ) {
      MIDI.sendControlChange(51, newZ & 0x7F, 1);
      MIDI.sendControlChange(19, (newZ >> 7) & 0x7F, 1);
    }
    #endif

      lastW = newW;
      lastX = newX;
      lastY = newY;
      lastZ = newZ;
    }
    else //send yaw pitch roll data
    {

      quat2ypr(ypr, &quat);
      newZ = (uint16_t)(radTo14 * ((ypr[0] + pi)));
      newY = (uint16_t)(radTo14 * ((ypr[1] + pi)));
      newX = (uint16_t)(radTo14 * ((ypr[2] + pi)));
    
    #ifdef MODE_SERIAL
    if (newZ != lastZ || newY != lastY || newX != lastX ) {
      
      sendYPR(newZ, newY, newX);
      
    }
    #endif
    
    #ifdef MODE_MIDI
    if (newZ != lastZ) {  
      MIDI.sendControlChange(48, newZ & 0x7F,  1);
      MIDI.sendControlChange(16, (newZ >> 7) & 0x7F, 1);
    }
    if (newY != lastY) {
      MIDI.sendControlChange(49, newY & 0x7F, 1);
      MIDI.sendControlChange(17, (newY >> 7) & 0x7F, 1);  
    }
    if (newX != lastX) {
      MIDI.sendControlChange(50, newX & 0x7F, 1);
      MIDI.sendControlChange(18, (newX >> 7) & 0x7F, 1);
    }
    #endif

      
      lastX = newX;
      lastY = newY;
      lastZ = newZ;
    }


    mpu.resetFIFO();
  }


  // ============== BUTTON ACTION ROUTINE ======================
  
  //now do some action!
  switch (action) {
    case 1: // short button click
      if (calibrationState == 1) {
        vGravCal = VectorFloat(gRaw.x, gRaw.y, gRaw.z);
        calibrate();
        calibrationState = 0;
      }
      else {
        qIdleConj = qRaw.getConjugate();
      }
      break;
    case 2: // long hold
      if (!calibrationState) {
        calibrationState = 1;
        qIdleConj = qRaw.getConjugate();
        vGravIdle = VectorFloat(gRaw.x, gRaw.y, gRaw.z);
      }
  }

}

void calibrate() {
  VectorFloat g, gCal, x, y, z;
  //g = refVector.getRotated(&qGravIdle); //g = qGravIdle.rotateVector(refVector);
  g = vGravIdle;
  z = g; // z = opposite(g); not necessary
  z.normalize();

  //gCal = refVector.getRotated(&qGravCal); //gCal = qGravCal.rotateVector(refVector);
  gCal = vGravCal;
  y = cross(gCal, g);
  y.normalize();

  x = cross(y, z);
  x.normalize();

  imu::Matrix<3> rot;
  rot.cell(0, 0) = x.x;
  rot.cell(1, 0) = x.y;
  rot.cell(2, 0) = x.z;
  rot.cell(0, 1) = y.x;
  rot.cell(1, 1) = y.y;
  rot.cell(2, 1) = y.z;
  rot.cell(0, 2) = z.x;
  rot.cell(1, 2) = z.y;
  rot.cell(2, 2) = z.z;

  qCal = RotMat2Quat(rot);
  EEPROM.put(qCalAddr, qCal);

  resetOrientation();
}

void buttonChange() {
  lastChangeTime = millis();
  buttonState = digitalRead(button);
  newButtonState = 1;
}

void resetOrientation() {
  qCalLeft = qCal.getConjugate();
  qCalRight = qCal;
}

VectorFloat opposite(VectorFloat v) {
  v.x *= -1;
  v.y *= -1;
  v.z *= -1;
  return v;
}

VectorFloat cross(VectorFloat p, VectorFloat v)
{
  VectorFloat ret;
  ret.x = p.y * v.z - p.z * v.y;
  ret.y = p.z * v.x - p.x * v.z;
  ret.z = p.x * v.y - p.y * v.x;
  return ret;
}


Quaternion RotMat2Quat(imu::Matrix<3>& m)
{
  Quaternion ret;
  double tr = m.trace();

  double S;
  if (tr > 0)
  {
    S = sqrt(tr + 1.0) * 2;
    ret.w = 0.25 * S;
    ret.x = (m(2, 1) - m(1, 2)) / S;
    ret.y = (m(0, 2) - m(2, 0)) / S;
    ret.z = (m(1, 0) - m(0, 1)) / S;
  }
  else if (m(0, 0) > m(1, 1) && m(0, 0) > m(2, 2))
  {
    S = sqrt(1.0 + m(0, 0) - m(1, 1) - m(2, 2)) * 2;
    ret.w = (m(2, 1) - m(1, 2)) / S;
    ret.x = 0.25 * S;
    ret.y = (m(0, 1) + m(1, 0)) / S;
    ret.z = (m(0, 2) + m(2, 0)) / S;
  }
  else if (m(1, 1) > m(2, 2))
  {
    S = sqrt(1.0 + m(1, 1) - m(0, 0) - m(2, 2)) * 2;
    ret.w = (m(0, 2) - m(2, 0)) / S;
    ret.x = (m(0, 1) + m(1, 0)) / S;
    ret.y = 0.25 * S;
    ret.z = (m(1, 2) + m(2, 1)) / S;
  }
  else
  {
    S = sqrt(1.0 + m(2, 2) - m(0, 0) - m(1, 1)) * 2;
    ret.w = (m(1, 0) - m(0, 1)) / S;
    ret.x = (m(0, 2) + m(2, 0)) / S;
    ret.y = (m(1, 2) + m(2, 1)) / S;
    ret.z = 0.25 * S;
  }
  return ret;
}

void quat2ypr(float *ypr, Quaternion *q) {
  //CONVERSION FROM QUATERNION DATA TO TAIT-BRYAN ANGLES yaw, pitch and roll
  //IMPORTANT: rotation order: yaw, pitch, roll (intrinsic rotation: z-y'-x'') !!
  //MNEMONIC: swivel on your swivel chair, look up/down, then tilt your head left/right...
  //           ... thats how we yaw, pitch'n'roll.
  double ysqr = q->y * q->y;

  // yaw (z-axis rotation)
  double t0 = 2.0 * (q->w * q->z + q->x * q->y);
  double t1 = 1.0 - 2.0 * (ysqr + q->z * q->z);
  ypr[0] = atan2(t0, t1);

  // pitch (y-axis rotation)
  t0 = 2.0 * (q->w * q->y - q->z * q->x);
  t0 = t0 > 1.0 ? 1.0 : t0;
  t0 = t0 < -1.0 ? -1.0 : t0;
  ypr[1] = asin(t0);

  // roll (x-axis rotation)
  t0 = 2.0 * (q->w * q->x + q->y * q->z);
  t1 = 1.0 - 2.0 * (q->x * q->x + ysqr);
  ypr[2] = atan2(t0, t1);
}

void sendQuaternion(uint16_t qW, uint16_t qX, uint16_t qY, uint16_t qZ){


  Serial.print(qW);
  Serial.print(' ');
  Serial.print(qX);
  Serial.print(' ');
  Serial.print(qY);
  Serial.print(' ');
  Serial.print(qZ);
  Serial.print('\n');

}

void sendYPR(uint16_t yaw, uint16_t pitch, uint16_t roll){

  Serial.print(yaw);
  Serial.print(' ');
  Serial.print(pitch);
  Serial.print(' ');
  Serial.print(roll);
  Serial.print('\n');

}

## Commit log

2021-02-03 [initial commit]
    [HeadTracker.fzz, HeadTrackerEnclosure_Button.stl, HeadTrackerEnclosure_HeadphoneClip (1).stl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]
2021-03-18 [update] enclosure
    [HeadTrackerEnclosure_Button.stl, HeadTrackerEnclosure_HeadphoneClip (1).stl, HeadTrackerEnclosure_HeadphoneClip.stl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]
2022-04-04 [add] serial quaternion handling
    [APL-logo.dxf, HeadTrackerEnclosure_Button.stl, HeadTrackerEnclosure_HeadphoneClip (1).stl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]
2022-07-04 [rename] arduino file
2022-07-04 [add] new enclosure 3d files
    [APL-logo.dxf, HeadTracker.fzz, HeadTrackerEnclosure_Button.stl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]

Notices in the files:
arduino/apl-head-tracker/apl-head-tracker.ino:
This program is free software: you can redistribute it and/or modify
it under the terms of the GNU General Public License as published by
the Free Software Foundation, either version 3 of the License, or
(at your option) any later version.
